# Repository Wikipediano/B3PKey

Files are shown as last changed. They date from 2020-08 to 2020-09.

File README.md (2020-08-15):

# B3PKey
 This is the first custom keyboard that I have designed.
 It is an ortholinear 75% keyboard which, when completed, will have been entirely designed and built by me.
 
 I have been inspired to do this project by <a href="https://www.reddit.com/user/JustOneMorePixel">u/JustOneMorePixel</a>, and I have gone through ai03's book <a href="https://wiki.ai03.com/books/pcb-design">*PCB Design*</a> and Hadi Iskandarani's YouTube series <a href="https://www.youtube.com/playlist?list=PLbtY7JsOJDYkHNuTmBtGgaWv_qipKeL-u">*PCB Design for Mechanical Keyboards*</a>.

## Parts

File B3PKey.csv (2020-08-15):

Reference | Quantity | Value | Footprint | Datasheet
C2 C1 | 2 | 22pF | Capacitor_SMD:C_0805_2012Metric | ~
C3 | 1 | 1uF | Capacitor_SMD:C_0805_2012Metric | ~
C4 C5 C6 | 3 | 0.1uF | Capacitor_SMD:C_0805_2012Metric | ~
C7 | 1 | 10uF | Capacitor_SMD:C_0805_2012Metric | ~
D80 D79 D78 D77 D76 D75 D74 D73 D72 D71 D70 D56 D57 D58 D59 D60 D61 D62 D63 D64 D65 D66 D67 D68 D69 D55 D54 D53 D52 D51 D50 D49 D48 D47 D46 D45 D44 D43 D42 D41 D40 D39 D38 D37 D36 D35 D34 D33 D32 D31 D30 D29 D15 D16 D17 D18 D19 D20 D21 D22 D23 D24 D25 D26 D27 D28 D14 D13 D12 D11 D10 D9 D8 D7 D6 D5 D4 D3 D2 D1 D81 | 81 | D_Small | Diode_SMD:D_SOD-123 | ~
F1 | 1 | 500mA | Fuse:Fuse_0805_2012Metric | ~
MX55 | 1 | MX-NoLED | MX_Only:MXOnly-2U-NoLED
MX73 MX72 MX71 MX70 MX56 MX57 MX58 MX59 MX60 MX61 MX62 MX63 MX64 MX65 MX66 MX67 MX68 MX69 MX54 MX53 MX52 MX51 MX50 MX49 MX48 MX47 MX46 MX45 MX44 MX43 MX36 MX35 MX34 MX33 MX32 MX31 MX30 MX29 MX15 MX16 MX17 MX18 MX19 MX20 MX21 MX22 MX23 MX24 MX25 MX26 MX27 MX28 MX14 MX13 MX12 MX11 MX10 MX9 MX8 MX7 MX6 MX5 MX4 MX3 MX2 MX1 MX42 MX41 MX40 MX39 MX38 MX37 MX81 MX76 MX77 MX78 MX79 MX80 | 78 | MX-NoLED | MX_Only:MXOnly-1U-NoLED
MX74 MX75 | 2 | MX-NoLED | MX_Only:MXOnly-2U-ReversedStabilizers-NoLED
R2 R3 | 2 | 22 | Resistor_SMD:R_0805_2012Metric | ~
R4 R1 | 2 | 10k | Resistor_SMD:R_0805_2012Metric | ~
SW1 | 1 | SW_Push | random-keyboard-parts:SKQG-1155865 | ~
U1 | 1 | ATmega32U4-AU | Package_QFP:TQFP-44_10x10mm_P0.8mm | http://ww1.microchip.com/downloads/en/DeviceDoc/Atmel-7766-8-bit-AVR-ATmega16U4-32U4_Datasheet.pdf
USB1 | 1 | Molex-0548190589 | random-keyboard-parts:Molex-0548190589
Y1 | 1 | 16MHz | Crystal:Crystal_SMD_3225-4Pin_3.2x2.5mm | ~

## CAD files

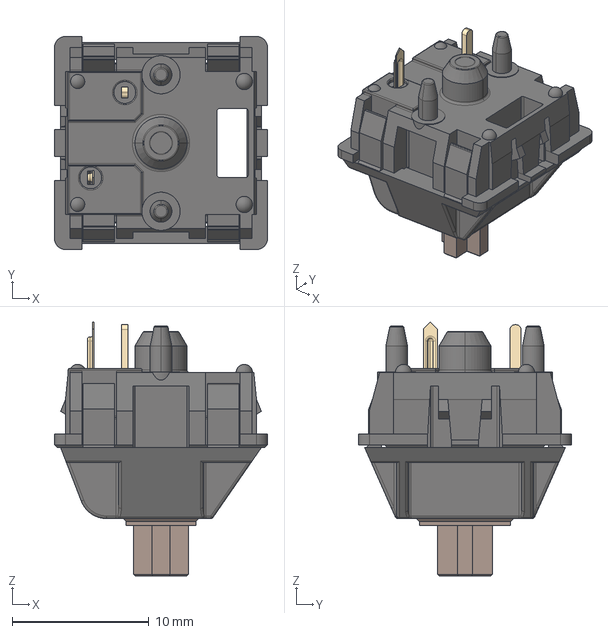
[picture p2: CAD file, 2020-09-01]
MX_SWITCH_3D/ASM_MX_ASM_cp.step
15.6 x 15.6 x 18.6 mm

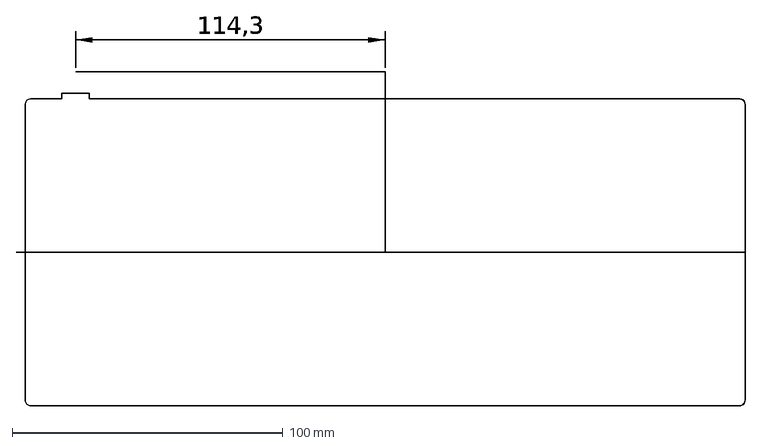
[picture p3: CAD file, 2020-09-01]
case_open.dxf
114,3

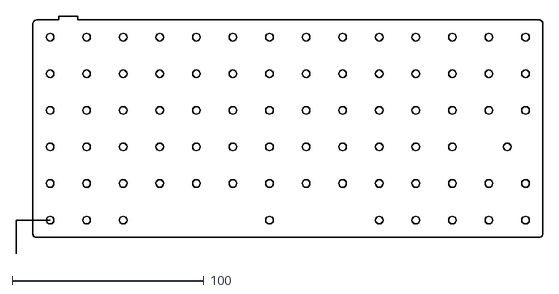
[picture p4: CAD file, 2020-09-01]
pcboutlinev3.dxf
274.3 x 123.9

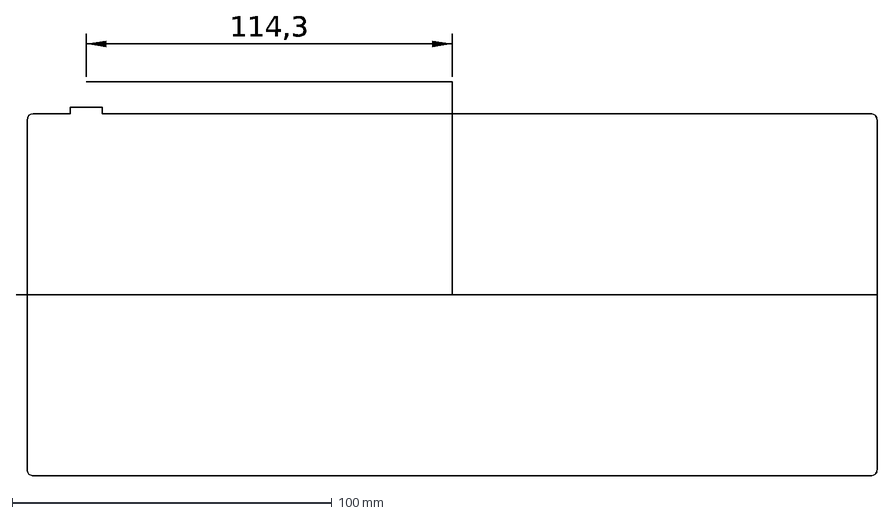
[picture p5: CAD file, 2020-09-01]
outline2.dxf
114,3

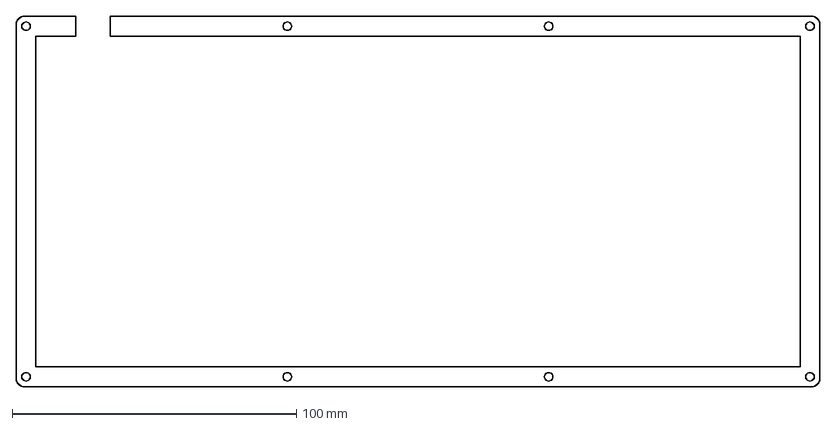
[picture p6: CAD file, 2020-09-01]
caseoutlinev2.dxf
282.7 x 130.3 mm

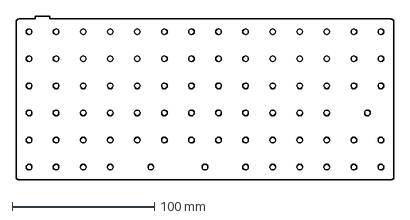
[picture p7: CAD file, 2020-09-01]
outlinewkeys.dxf
265.7 x 115.3 mm

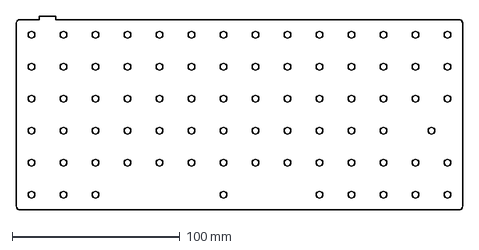
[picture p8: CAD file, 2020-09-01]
outlinewkeysnew.dxf
265.7 x 115.3 mm

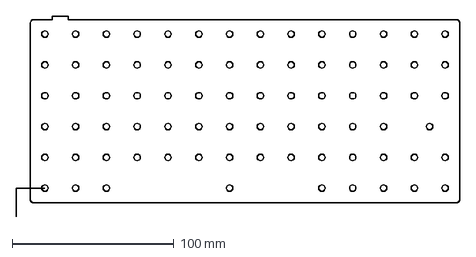
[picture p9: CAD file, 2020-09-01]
pcboutlinev2.dxf
274.3 x 123.9 mm

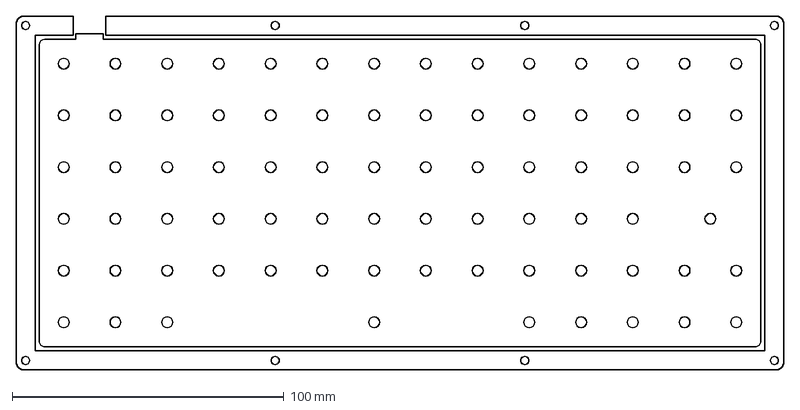
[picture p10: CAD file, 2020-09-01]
outlinewkeysandcaseopenlayer.dxf
282.7 x 130.3 mm

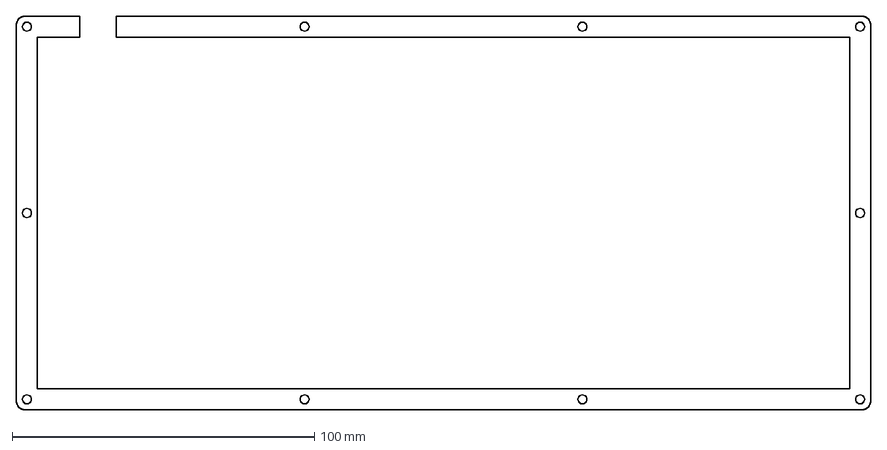
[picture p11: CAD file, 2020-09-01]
Case_Open_v5.dxf
282.7 x 130.3 mm

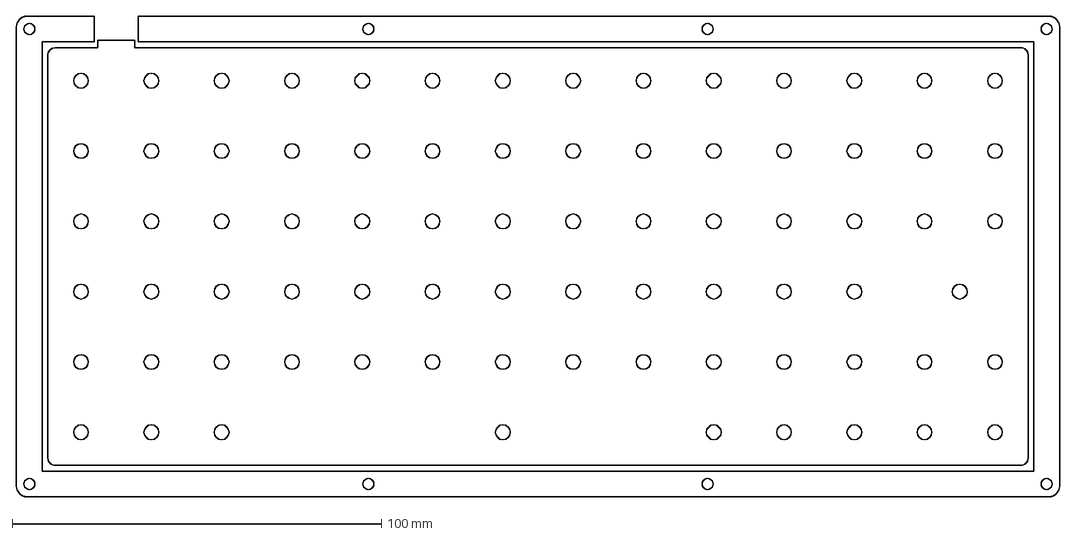
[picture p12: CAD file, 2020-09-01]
outlinewkeysandcaseopenlayer 2 this one is the newest one.dxf
282.7 x 130.3 mm

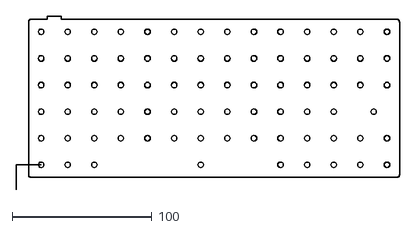
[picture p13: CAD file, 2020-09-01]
pcboutlinev4.dxf
274.3 x 123.9

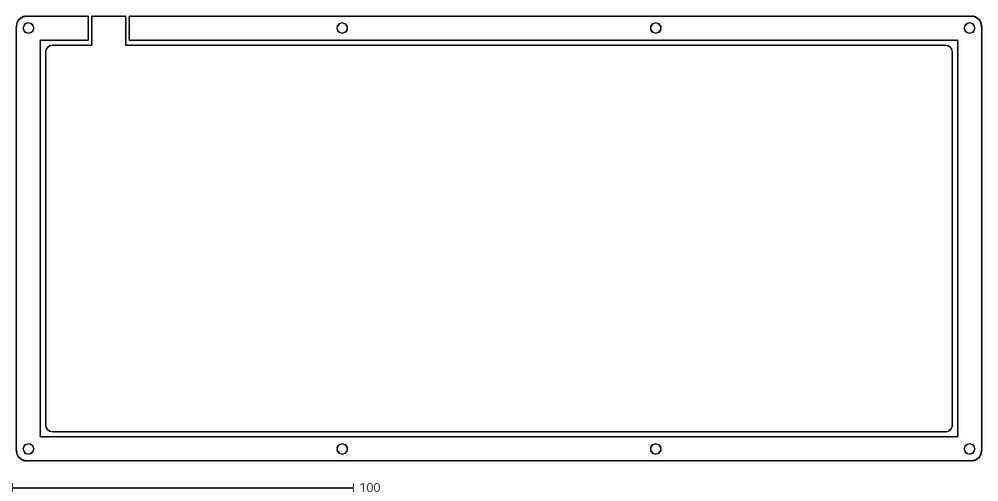
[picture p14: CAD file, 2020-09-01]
B3PKey-Edge_Cuts.dxf
282.7 x 130.3

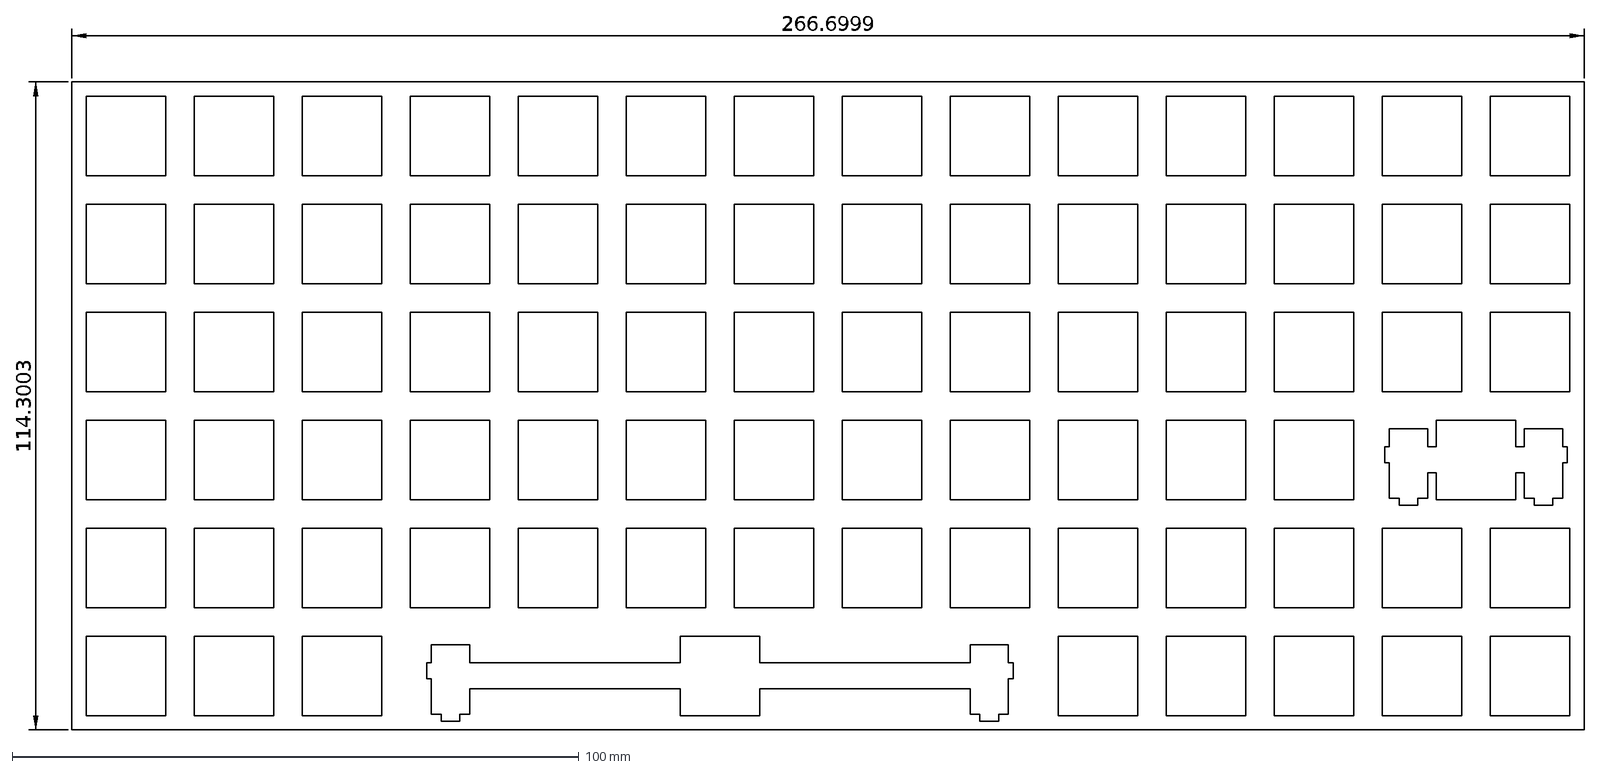
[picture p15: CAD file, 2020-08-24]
plate.dxf
266.6999
114.3003

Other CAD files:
keyreference.dxf
outlinewkeys_newsize.dxf

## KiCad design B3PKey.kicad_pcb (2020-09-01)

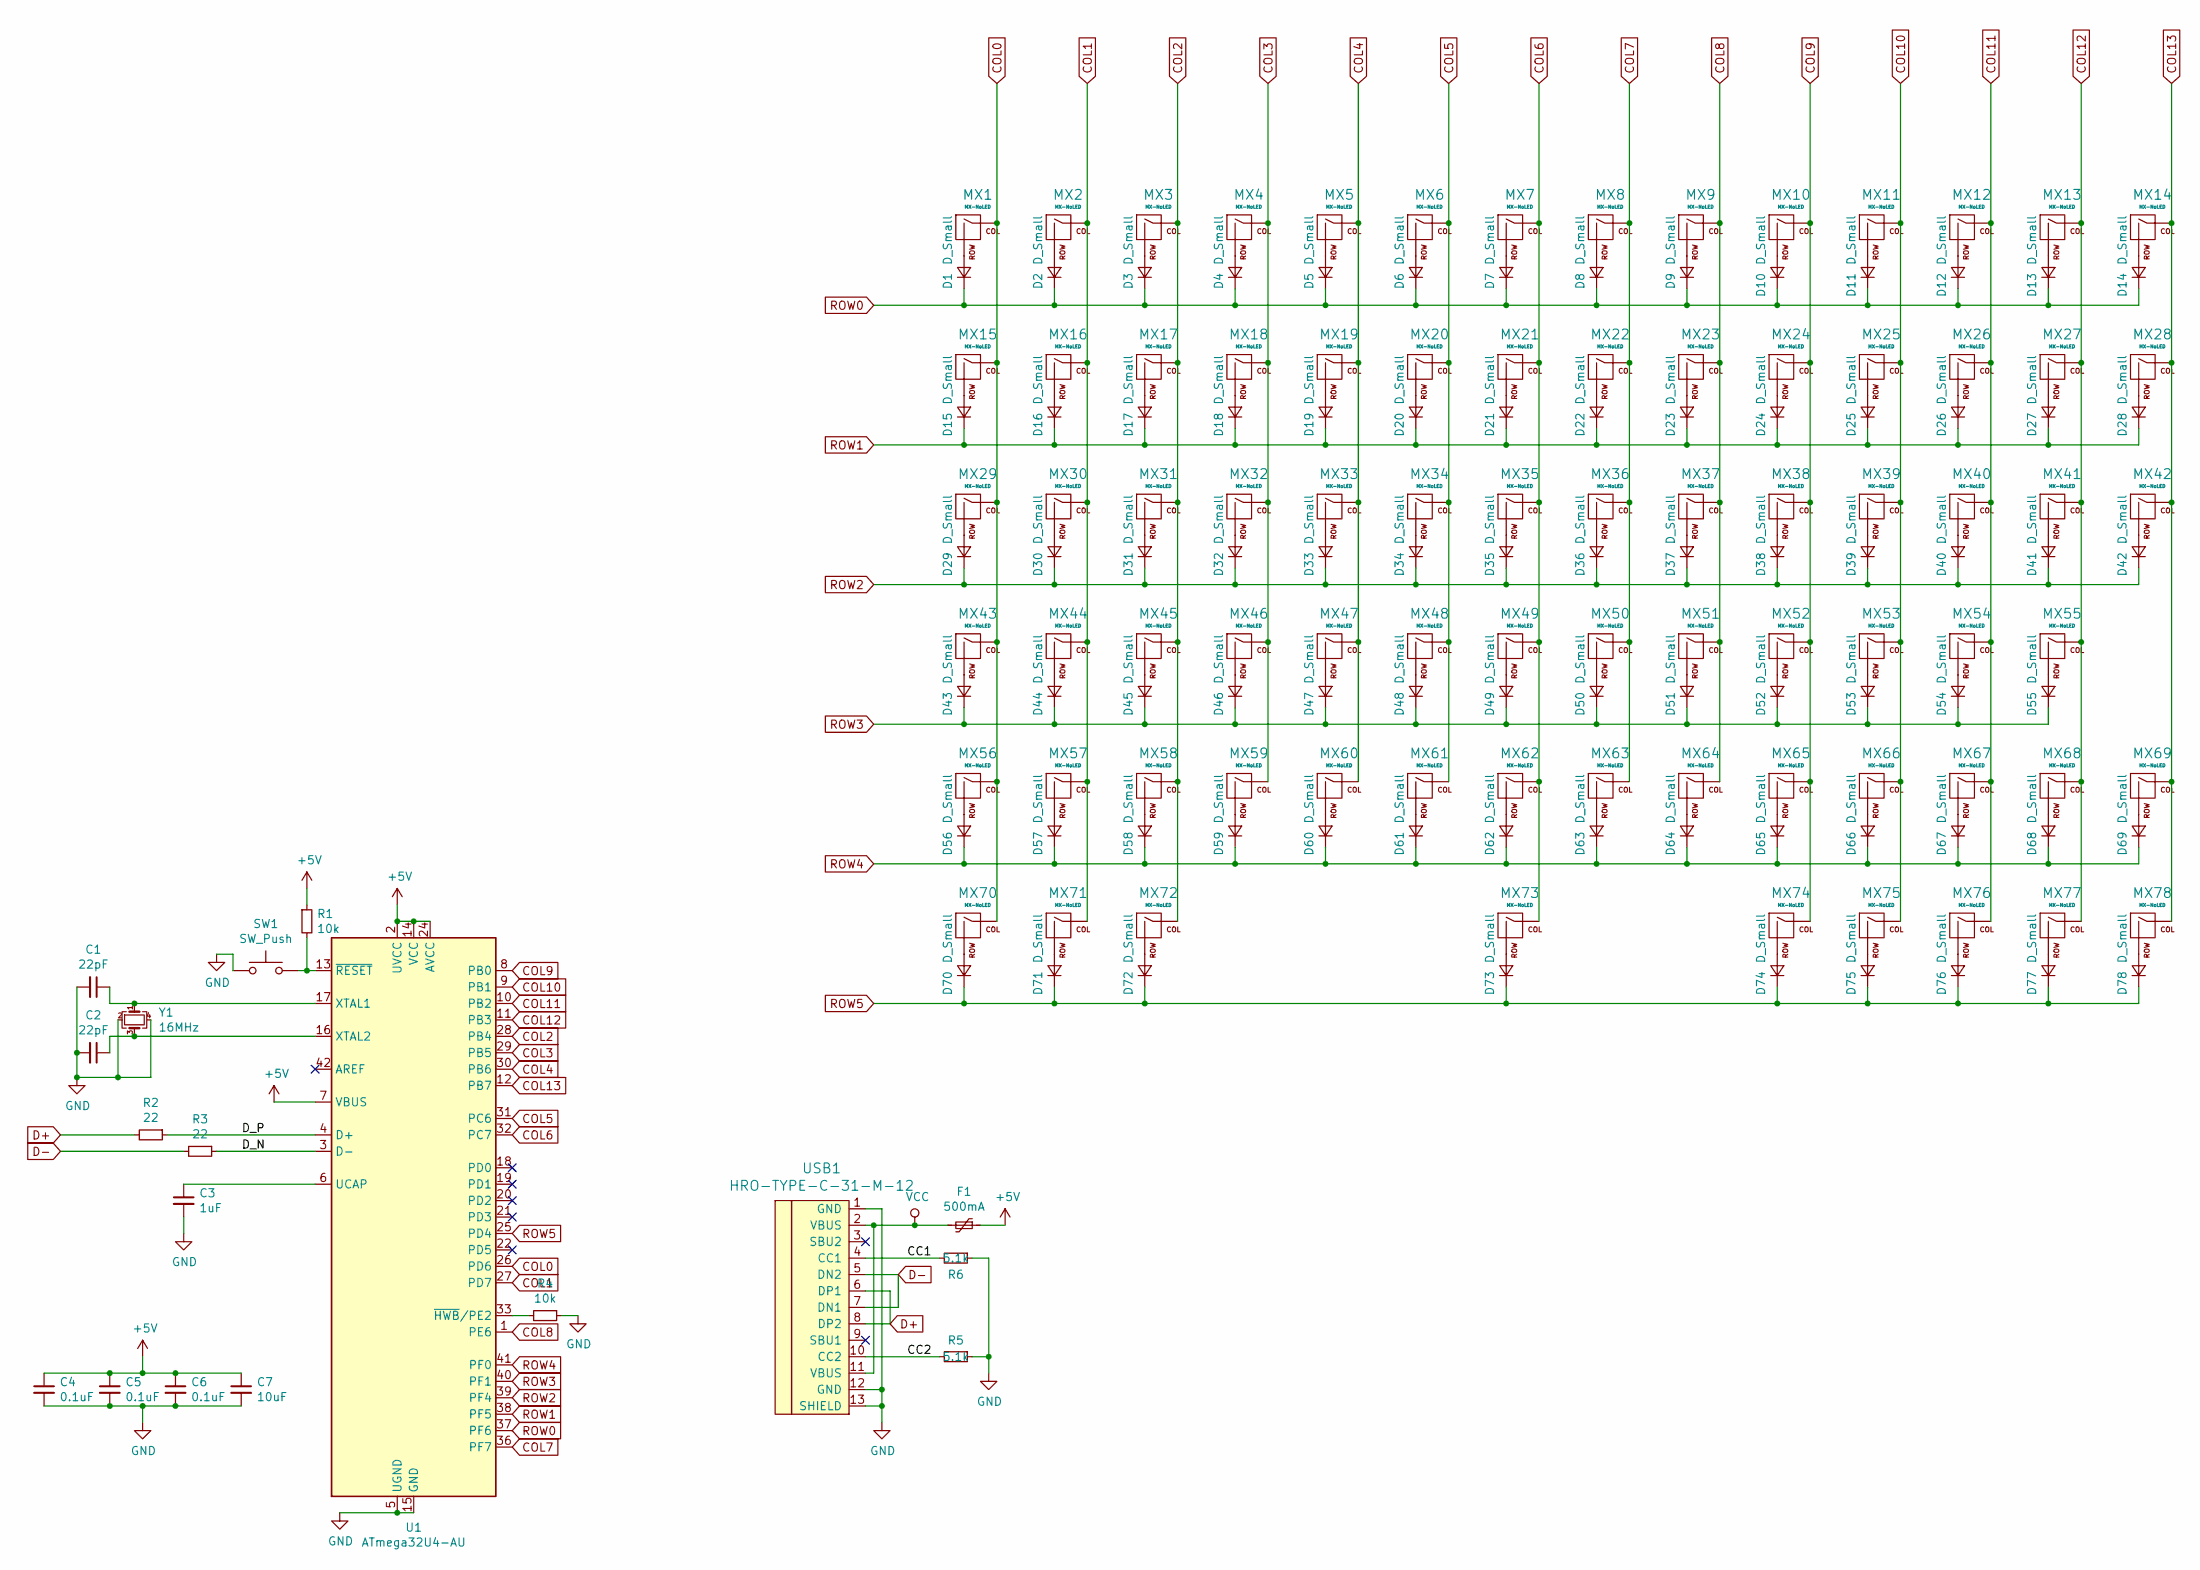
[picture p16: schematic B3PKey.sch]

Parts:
C1, C2: 22pF; C_0805_2012Metric
C3: 1uF; C_0805_2012Metric
C4, C5, C6: 0.1uF; C_0805_2012Metric
C7: 10uF; C_0805_2012Metric
D1, D2, D3, D4, D5, D6, D7, D8, D9, D10, D11, D12, D13, D14, D15, D16, D17, D18, D19, D20, D21, D22, D23, D24, D25, D26, D27, D28, D29, D30, D31, D32, D33, D34, D35, D36, D37, D38, D39, D40, D41, D42, D43, D44, D45, D46, D47, D48, D49, D50, D51, D52, D53, D54, D55, D56, D57, D58, D59, D60, D61, D62, D63, D64, D65, D66, D67, D68, D69, D70, D71, D72, D73, D74, D75, D76, D77, D78: D_Small; D_SOD-123
F1: 500mA; Fuse_0805_2012Metric
MX1, MX2, MX3, MX4, MX5, MX6, MX7, MX8, MX9, MX10, MX11, MX12, MX13, MX14, MX15, MX16, MX17, MX18, MX19, MX20, MX21, MX22, MX23, MX24, MX25, MX26, MX27, MX28, MX29, MX30, MX31, MX32, MX33, MX34, MX35, MX36, MX37, MX38, MX39, MX40, MX41, MX42, MX43, MX44, MX45, MX46, MX47, MX48, MX49, MX50, MX51, MX52, MX53, MX54, MX56, MX57, MX58, MX59, MX60, MX61, MX62, MX63, MX64, MX65, MX66, MX67, MX68, MX69, MX70, MX71, MX72, MX74, MX75, MX76, MX77, MX78: MX-NoLED; MXOnly-1U-NoLED
MX55: MX-NoLED; MXOnly-2U-NoLED
MX73: MX-NoLED; MXOnly-6U-ReversedStabilizers-NoLED
R1, R4: 10k; R_0805_2012Metric
R2, R3: 22; R_0805_2012Metric
R5, R6: 5.1k; R_0805_2012Metric
SW1: SW_Push; SKQG-1155865
U1: ATmega32U4-AU; TQFP-44_10x10mm_P0.8mm
USB1: HRO-TYPE-C-31-M-12; HRO-TYPE-C-31-M-12-HandSoldering
Y1: 16MHz; Crystal_SMD_3225-4Pin_3.2x2.5mm

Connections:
+5V: C4.1, C5.1, C6.1, C7.1, F1.1, R1.1, U1.2 (UVCC), U1.7 (VBUS), U1.14 (VCC), U1.24 (AVCC), U1.34 (VCC), U1.44 (AVCC)
/CC1: R6.2, USB1.4 (CC1)
/CC2: R5.2, USB1.10 (CC2)
/D_N: R3.1, U1.3 (D-)
/D_P: R2.1, U1.4 (D+)
COL0: MX1.1 (COL), MX15.1 (COL), MX29.1 (COL), MX43.1 (COL), MX56.1 (COL), MX70.1 (COL), U1.26 (PD6)
COL1: MX2.1 (COL), MX16.1 (COL), MX30.1 (COL), MX44.1 (COL), MX57.1 (COL), MX71.1 (COL), U1.27 (PD7)
COL2: MX3.1 (COL), MX17.1 (COL), MX31.1 (COL), MX45.1 (COL), MX58.1 (COL), MX72.1 (COL), U1.28 (PB4)
COL3: MX4.1 (COL), MX18.1 (COL), MX32.1 (COL), MX46.1 (COL), MX59.1 (COL), U1.29 (PB5)
COL4: MX5.1 (COL), MX19.1 (COL), MX33.1 (COL), MX47.1 (COL), MX60.1 (COL), U1.30 (PB6)
COL5: MX6.1 (COL), MX20.1 (COL), MX34.1 (COL), MX48.1 (COL), MX61.1 (COL), U1.31 (PC6)
COL6: MX7.1 (COL), MX21.1 (COL), MX35.1 (COL), MX49.1 (COL), MX62.1 (COL), MX73.1 (COL), U1.32 (PC7)
COL7: MX8.1 (COL), MX22.1 (COL), MX36.1 (COL), MX50.1 (COL), MX63.1 (COL), U1.36 (PF7)
COL8: MX9.1 (COL), MX23.1 (COL), MX37.1 (COL), MX51.1 (COL), MX64.1 (COL), U1.1 (PE6)
COL9: MX10.1 (COL), MX24.1 (COL), MX38.1 (COL), MX52.1 (COL), MX65.1 (COL), MX74.1 (COL), U1.8 (PB0)
COL10: MX11.1 (COL), MX25.1 (COL), MX39.1 (COL), MX53.1 (COL), MX66.1 (COL), MX75.1 (COL), U1.9 (PB1)
COL11: MX12.1 (COL), MX26.1 (COL), MX40.1 (COL), MX54.1 (COL), MX67.1 (COL), MX76.1 (COL), U1.10 (PB2)
COL12: MX13.1 (COL), MX27.1 (COL), MX41.1 (COL), MX55.1 (COL), MX68.1 (COL), MX77.1 (COL), U1.11 (PB3)
COL13: MX14.1 (COL), MX28.1 (COL), MX42.1 (COL), MX69.1 (COL), MX78.1 (COL), U1.12 (PB7)
D+: R2.2, USB1.6 (DP1), USB1.8 (DP2)
D-: R3.2, USB1.5 (DN2), USB1.7 (DN1)
GND: C1.2, C2.2, C3.2, C4.2, C5.2, C6.2, C7.2, R4.1, R5.1, R6.1, SW1.1, U1.5 (UGND), U1.15 (GND), U1.23 (GND), U1.35 (GND), U1.43 (GND), USB1.1 (GND), USB1.12 (GND), USB1.13 (SHIELD), Y1.2, Y1.4
unnamed: C1.1, U1.17 (XTAL1), Y1.1
unnamed: C2.1, U1.16 (XTAL2), Y1.3
unnamed: C3.1, U1.6 (UCAP)
unnamed: D1.2 (A), MX1.2 (ROW)
unnamed: D2.2 (A), MX2.2 (ROW)
unnamed: D3.2 (A), MX3.2 (ROW)
unnamed: D4.2 (A), MX4.2 (ROW)
unnamed: D5.2 (A), MX5.2 (ROW)
unnamed: D6.2 (A), MX6.2 (ROW)
unnamed: D7.2 (A), MX7.2 (ROW)
unnamed: D8.2 (A), MX8.2 (ROW)
unnamed: D9.2 (A), MX9.2 (ROW)
unnamed: D10.2 (A), MX10.2 (ROW)
unnamed: D11.2 (A), MX11.2 (ROW)
unnamed: D12.2 (A), MX12.2 (ROW)
unnamed: D13.2 (A), MX13.2 (ROW)
unnamed: D14.2 (A), MX14.2 (ROW)
unnamed: D15.2 (A), MX15.2 (ROW)
unnamed: D16.2 (A), MX16.2 (ROW)
unnamed: D17.2 (A), MX17.2 (ROW)
unnamed: D18.2 (A), MX18.2 (ROW)
unnamed: D19.2 (A), MX19.2 (ROW)
unnamed: D20.2 (A), MX20.2 (ROW)
unnamed: D21.2 (A), MX21.2 (ROW)
unnamed: D22.2 (A), MX22.2 (ROW)
unnamed: D23.2 (A), MX23.2 (ROW)
unnamed: D24.2 (A), MX24.2 (ROW)
unnamed: D25.2 (A), MX25.2 (ROW)
unnamed: D26.2 (A), MX26.2 (ROW)
unnamed: D27.2 (A), MX27.2 (ROW)
unnamed: D28.2 (A), MX28.2 (ROW)
unnamed: D29.2 (A), MX29.2 (ROW)
unnamed: D30.2 (A), MX30.2 (ROW)
unnamed: D31.2 (A), MX31.2 (ROW)
unnamed: D32.2 (A), MX32.2 (ROW)
unnamed: D33.2 (A), MX33.2 (ROW)
unnamed: D34.2 (A), MX34.2 (ROW)
unnamed: D35.2 (A), MX35.2 (ROW)
unnamed: D36.2 (A), MX36.2 (ROW)
unnamed: D37.2 (A), MX37.2 (ROW)
unnamed: D38.2 (A), MX38.2 (ROW)
unnamed: D39.2 (A), MX39.2 (ROW)
unnamed: D40.2 (A), MX40.2 (ROW)
unnamed: D41.2 (A), MX41.2 (ROW)
unnamed: D42.2 (A), MX42.2 (ROW)
unnamed: D43.2 (A), MX43.2 (ROW)
unnamed: D44.2 (A), MX44.2 (ROW)
unnamed: D45.2 (A), MX45.2 (ROW)
unnamed: D46.2 (A), MX46.2 (ROW)
unnamed: D47.2 (A), MX47.2 (ROW)
unnamed: D48.2 (A), MX48.2 (ROW)
unnamed: D49.2 (A), MX49.2 (ROW)
unnamed: D50.2 (A), MX50.2 (ROW)
unnamed: D51.2 (A), MX51.2 (ROW)
unnamed: D52.2 (A), MX52.2 (ROW)
unnamed: D53.2 (A), MX53.2 (ROW)
unnamed: D54.2 (A), MX54.2 (ROW)
unnamed: D55.2 (A), MX55.2 (ROW)
unnamed: D56.2 (A), MX56.2 (ROW)
unnamed: D57.2 (A), MX57.2 (ROW)
unnamed: D58.2 (A), MX58.2 (ROW)
unnamed: D59.2 (A), MX59.2 (ROW)
unnamed: D60.2 (A), MX60.2 (ROW)
unnamed: D61.2 (A), MX61.2 (ROW)
unnamed: D62.2 (A), MX62.2 (ROW)
unnamed: D63.2 (A), MX63.2 (ROW)
unnamed: D64.2 (A), MX64.2 (ROW)
unnamed: D65.2 (A), MX65.2 (ROW)
unnamed: D66.2 (A), MX66.2 (ROW)
unnamed: D67.2 (A), MX67.2 (ROW)
unnamed: D68.2 (A), MX68.2 (ROW)
unnamed: D69.2 (A), MX69.2 (ROW)
unnamed: D70.2 (A), MX70.2 (ROW)
unnamed: D71.2 (A), MX71.2 (ROW)
unnamed: D72.2 (A), MX72.2 (ROW)
unnamed: D73.2 (A), MX73.2 (ROW)
unnamed: D74.2 (A), MX74.2 (ROW)
unnamed: D75.2 (A), MX75.2 (ROW)
unnamed: D76.2 (A), MX76.2 (ROW)
unnamed: D77.2 (A), MX77.2 (ROW)
unnamed: D78.2 (A), MX78.2 (ROW)
unnamed: R1.2, SW1.2, U1.13 (~RESET)
unnamed: R4.2, U1.33 (~HWB~/PE2)
ROW0: D1.1 (K), D2.1 (K), D3.1 (K), D4.1 (K), D5.1 (K), D6.1 (K), D7.1 (K), D8.1 (K), D9.1 (K), D10.1 (K), D11.1 (K), D12.1 (K), D13.1 (K), D14.1 (K), U1.37 (PF6)
ROW1: D15.1 (K), D16.1 (K), D17.1 (K), D18.1 (K), D19.1 (K), D20.1 (K), D21.1 (K), D22.1 (K), D23.1 (K), D24.1 (K), D25.1 (K), D26.1 (K), D27.1 (K), D28.1 (K), U1.38 (PF5)
ROW2: D29.1 (K), D30.1 (K), D31.1 (K), D32.1 (K), D33.1 (K), D34.1 (K), D35.1 (K), D36.1 (K), D37.1 (K), D38.1 (K), D39.1 (K), D40.1 (K), D41.1 (K), D42.1 (K), U1.39 (PF4)
ROW3: D43.1 (K), D44.1 (K), D45.1 (K), D46.1 (K), D47.1 (K), D48.1 (K), D49.1 (K), D50.1 (K), D51.1 (K), D52.1 (K), D53.1 (K), D54.1 (K), D55.1 (K), U1.40 (PF1)
ROW4: D56.1 (K), D57.1 (K), D58.1 (K), D59.1 (K), D60.1 (K), D61.1 (K), D62.1 (K), D63.1 (K), D64.1 (K), D65.1 (K), D66.1 (K), D67.1 (K), D68.1 (K), D69.1 (K), U1.41 (PF0)
ROW5: D70.1 (K), D71.1 (K), D72.1 (K), D73.1 (K), D74.1 (K), D75.1 (K), D76.1 (K), D77.1 (K), D78.1 (K), U1.25 (PD4)
VCC: F1.2, USB1.2 (VBUS), USB1.11 (VBUS)

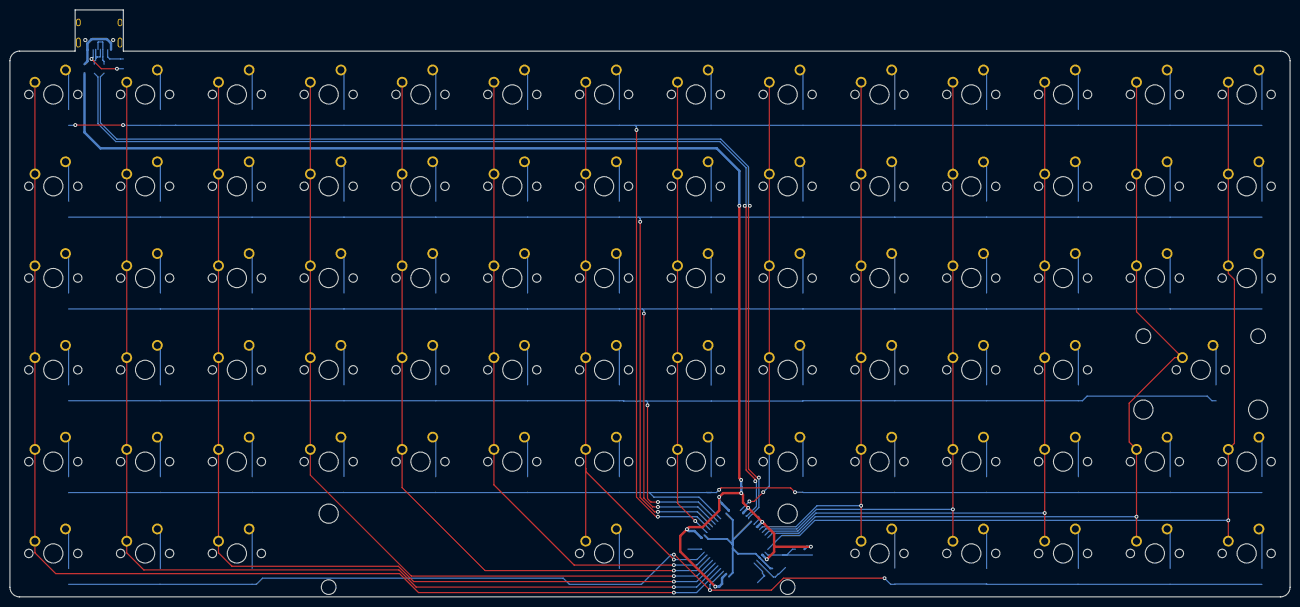
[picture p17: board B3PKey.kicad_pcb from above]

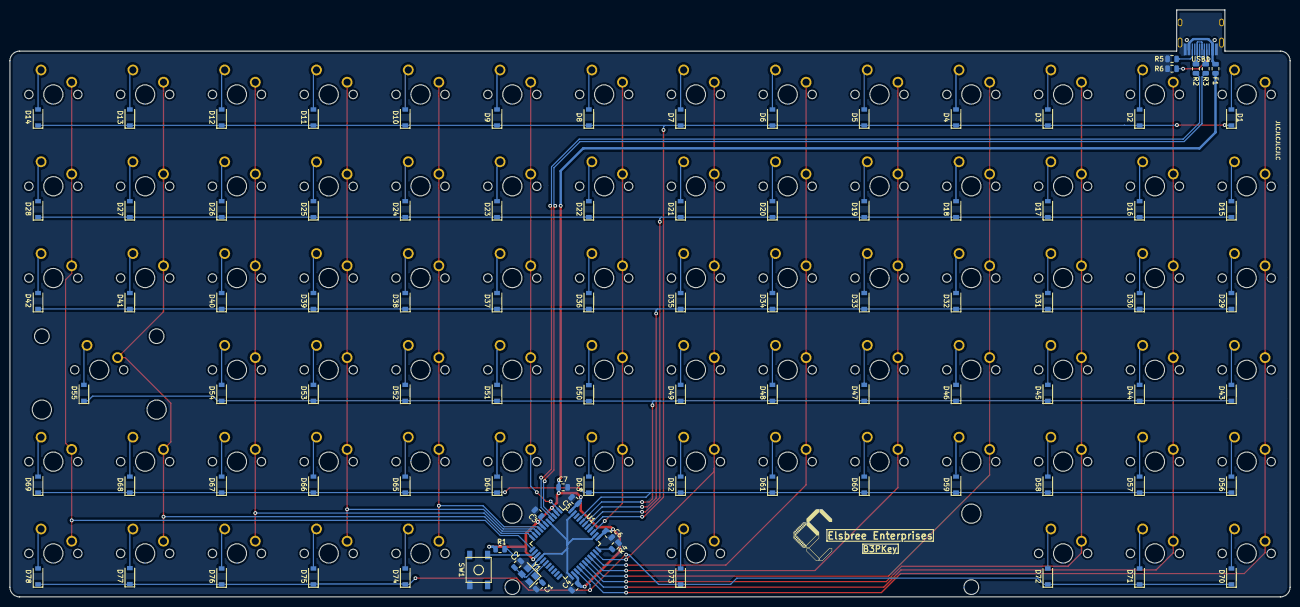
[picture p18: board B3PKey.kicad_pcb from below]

Board: 2 copper layers, 265.7 x 121.8 mm, 174 parts (96 on the bottom side), 112 nets.

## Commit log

2020-08-07 Controller and keyswitch schematic
    [B3PKey.sch]
2020-08-08 Updated switch matrix
    [B3PKey.sch]
2020-08-08 Keyswitch layout w/ diodes
    [B3PKey.sch]
2020-08-08 Flip spacebar stabs
    [B3PKey.kicad_pcb, B3PKey.sch]
2020-08-09 Matrix traces laid
    [B3PKey.kicad_pcb]
2020-08-09 Matrix traces tweak
    [B3PKey.kicad_pcb]
2020-08-10 Add Elite-C footprint
    [B3PKey.kicad_pcb]
2020-08-10 Update layout and replace microcontroller
    [B3PKey.kicad_pcb, B3PKey.sch]
2020-08-11 Modify silkscreen
    [B3PKey.kicad_pcb]
2020-08-11 Update layout
    [B3PKey.kicad_pcb, B3PKey.sch]
2020-08-11 Add border and reference files
    [keyreference.dxf, outline.dxf]
2020-08-11 Add edge cuts and place some components
    [B3PKey.kicad_pcb]
2020-08-11 Route USB traces
    [B3PKey.kicad_pcb, B3PKey.sch]
2020-08-13 Some routing
    [B3PKey.csv, B3PKey.kicad_pcb]
2020-08-13 Route more traces
    [B3PKey.kicad_pcb]
2020-08-14 Move components to forehead and route all traces
    [B3PKey.kicad_pcb, B3PKey.sch]
2020-08-14 Update placement and add edge cuts
    [B3PKey.kicad_pcb, outlinewkeys.dxf, outlinewkeys_newsize.dxf]
2020-08-15 Rotate controller and reroute traces
    [B3PKey.kicad_pcb, B3PKey.sch]
2020-08-15 Change to USB Type-C
    Changed the board to use a USB Type-C connector, added required components and modified ground plane to be neater. Also generated OUTDATED Gerber files.
    TODO: Generate new Gerbers
    [B3PKey-B_Cu.gbr, B3PKey-B_Mask.gbr, B3PKey-B_Paste.gbr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]
2020-08-15 Update traces and gerbers
    [B3PKey-B_Cu.gbr, B3PKey-B_Mask.gbr, B3PKey-B_Paste.gbr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]
2020-08-18 Move components to spacebar
    [B3PKey.sch]
2020-08-22 Update Gerbers
    [B3PKey-B_Cu.gbr, B3PKey-B_Mask.gbr, B3PKey-B_Paste.gbr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]
2020-08-24 Add silkscreen logo, update gerbers
    [B3PKey-B_Cu.gbr, B3PKey-B_Mask.gbr, B3PKey-B_Paste.gbr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]
2020-08-24 Update silkscreen
    [B3PKey.kicad_pcb]
2020-09-01 Update pbc outline, small tweaks
    Also generate new gerbers and add case_open dxf file
    [ASM_MX_ASM_cp.step, B3PKey-Edge_Cuts.dxf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]
2020-09-01 Update gerbers and outline
    [B3PKey-B_Cu.gbr, B3PKey-B_Mask.gbr, B3PKey-B_SilkS.gbr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]
